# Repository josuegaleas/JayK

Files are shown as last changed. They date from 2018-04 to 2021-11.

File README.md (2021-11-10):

# JayK
Full-size mechanical keyboard with USB-C and no lighting, inspired by the [ONO-SENDAI MATRIX 83](https://imgur.com/a/v5pzh#FiXKcm0).

JayK Pro with *more* features can be found [here](https://github.com/josuegaleas/JayK-Pro).

### Disclaimer
I have not printed this PCB out yet, and I am not 100% certain the design works. Please print with discretion.

## Features
- TMK-based firmware
- Numpad on the left for comfort
- USB-C port for modernness
- No lighting for less complexity and lower cost

## Layout
### Default Layer
Default Layer
### Other Layers
Other Layers

JSON files for these layouts can be found [here](https://gist.github.com/josuegaleas/417a4ff5fc216ecdc7868effc9a7b36f) and [here](https://gist.github.com/josuegaleas/c81fd5085f4eeaf2fcede5950b9f7410), for editing in [KLE](http://www.keyboard-layout-editor.com/).

## Major Components
- Microcontroller — [Microchip's AT90USB1286](https://www.microchip.com/wwwproducts/en/AT90USB1286)
- USB-C Port — [Amphenol's 12401610E4#2A](https://www.amphenol-icc.com/usb-3-1-type-c-gen-2-12401610e42a.html)
- Crystal — [EPSON's FA-238](https://www5.epsondevice.com/en/products/crystal_unit/fa238.html)

## Tools
- Layout — [Keyboard Layout Editor](http://www.keyboard-layout-editor.com/)
- PCB — [KiCad EDA](https://kicad.org/)
- Firmware
	- [tmk_core](https://github.com/tmk/tmk_core)
	- [avr-gcc](https://www.gnu.org/software/gcc/gcc.html)
	- [dfu-programmer](https://dfu-programmer.sourceforge.io/)
- Models — [Plate & Case Builder](http://builder.swillkb.com/)

### KiCad Libraries
- [kicad_lib_tmk](https://github.com/tmk/kicad_lib_tmk)
- [keyboard_parts.pretty](https://github.com/tmk/keyboard_parts.pretty)
- [keebs.pretty](https://github.com/egladman/keebs.pretty)
- [jay-kicad-lib](https://github.com/josuegaleas/jay-kicad-lib)

## Development
Clone this repository with:
```bash
git clone --recursive https://github.com/josuegaleas/JayK.git
```

### Hardware
Within KiCad, navigate to the `PCB` folder and open `JayK.pro`.

Using a grid size of `0.0234375` inches for editing the layout.

### Software
Firmware can be compiled using `make` within the `Firmware` folder.

Refer to [this](https://github.com/tmk/tmk_keyboard/blob/master/tmk_core/doc/build.md) for dependencies and programming.

## References
- Layout — [Physical Keyboard Layouts Explained In Detail](https://drop.com/talk/947/physical-keyboard-layouts-explained-in-detail)
- PCB
	- [Keyboard PCB Guide](https://github.com/ruiqimao/keyboard-pcb-guide)
	- [Teensy++ 2.0 USB Development Board](https://www.pjrc.com/store/teensypp.html)
	- [Microchip's AT90USBKEY](https://www.microchip.com/DevelopmentTools/ProductDetails/AT90USBKEY2)
- Firmware
	- [TMK Keyboard Firmware Collection](https://github.com/tmk/tmk_keyboard/)
	- [How to build your very own keyboard firmware](https://deskthority.net/viewtopic.php?f=7&t=7177&start=)

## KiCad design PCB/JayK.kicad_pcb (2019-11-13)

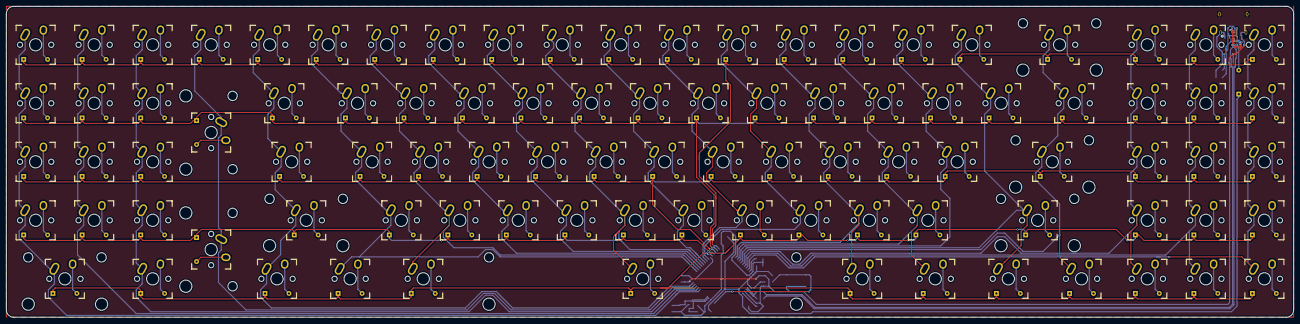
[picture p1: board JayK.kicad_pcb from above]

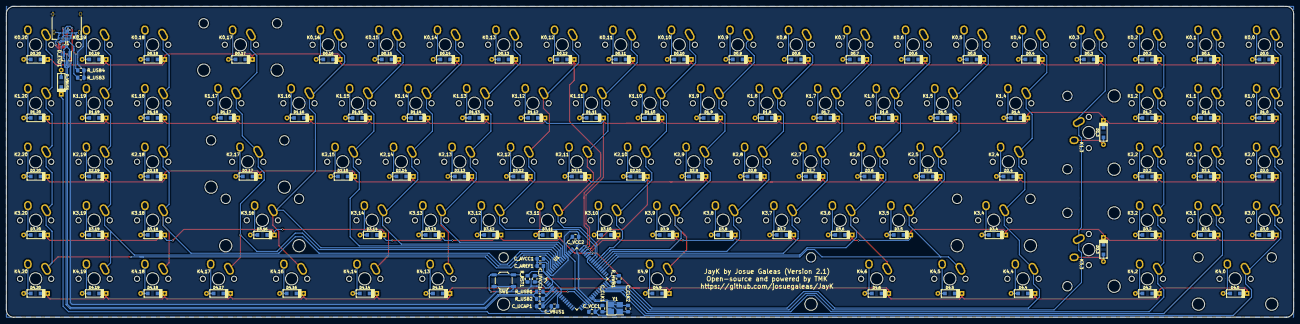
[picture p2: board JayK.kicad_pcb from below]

Board: 2 copper layers, 419.1 x 101.2 mm, 207 parts (114 on the bottom side), 134 nets.

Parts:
C_AREF1: 100n; C_0805_2012Metric_Pad1.15x1.40mm_HandSolder
C_AVCC1: 100n; C_0805_2012Metric_Pad1.15x1.40mm_HandSolder
C_CLK1, C_CLK2: 22p; C_0805_2012Metric_Pad1.15x1.40mm_HandSolder
C_UCAP1: 1u; C_0805_2012Metric_Pad1.15x1.40mm_HandSolder
C_UVCC1: 100n; C_0805_2012Metric_Pad1.15x1.40mm_HandSolder
C_VBUS1: 10u; C_0805_2012Metric_Pad1.15x1.40mm_HandSolder
C_VCC1, C_VCC2: 100n; C_0805_2012Metric_Pad1.15x1.40mm_HandSolder
D0,0, D0,1, D0,2, D0,3, D0,4, D0,5, D0,6, D0,7, D0,8, D0,9, D0,10, D0,11, D0,12, D0,13, D0,14, D0,15, D0,16, D0,17, D0,18, D0,19, D0,20, D1,0, D1,1, D1,2, D1,3, D1,4, D1,5, D1,6, D1,7, D1,8, D1,9, D1,10, D1,11, D1,12, D1,13, D1,14, D1,15, D1,16, D1,17, D1,18, D1,19, D1,20, D2,0, D2,1, D2,2, D2,4, D2,5, D2,6, D2,7, D2,8, D2,9, D2,10, D2,11, D2,12, D2,13, D2,14, D2,15, D2,17, D2,18, D2,19, D2,20, D3,0, D3,1, D3,2, D3,3, D3,4, D3,5, D3,6, D3,7, D3,8, D3,9, D3,10, D3,11, D3,12, D3,13, D3,14, D3,16, D3,18, D3,19, D3,20, D4,0, D4,2, D4,4, D4,5, D4,6, D4,9, D4,13, D4,14, D4,16, D4,17, D4,18, D4,19, D4,20: D; D_SOD123_axial
D_ESD1: PESD5V0L2BT; SOT-23_Handsoldering
D_VBUS1: D; D_SOD123_axial
J1: USB_C_Receptacle_USB2.0; USB_C_Receptacle_Amphenol_12401610E4-2A
K0,0, K0,1, K0,2, K0,3, K0,4, K0,5, K0,6, K0,7, K0,8, K0,9, K0,10, K0,11, K0,12, K0,13, K0,14, K0,15, K0,16, K0,18, K0,19, K0,20, K1,0, K1,1, K1,2, K1,5, K1,6, K1,7, K1,8, K1,9, K1,10, K1,11, K1,12, K1,13, K1,14, K1,15, K1,16, K1,18, K1,19, K1,20, K2,0, K2,1, K2,2, K2,5, K2,6, K2,7, K2,8, K2,9, K2,10, K2,11, K2,12, K2,13, K2,14, K2,15, K2,18, K2,19, K2,20, K3,0, K3,1, K3,2, K3,5, K3,6, K3,7, K3,8, K3,9, K3,10, K3,11, K3,12, K3,13, K3,14, K3,18, K3,19, K3,20, K4,2, K4,18, K4,19, K4,20: KEYSW; Mx_Alps_100
K0,17, K1,3, K3,3, K4,0: KEYSW; Mx_Alps_200
K1,4, K1,17: KEYSW; Mx_Alps_150
K2,4: KEYSW; Mx_Alps_175
K2,17, K3,4: KEYSW; Mx_Alps_225
K3,16: KEYSW; Mx_Alps_275
K4,4, K4,5, K4,6, K4,13, K4,14, K4,16, K4,17: KEYSW; Mx_Alps_125
K4,9: KEYSW; Mx_Alps_625
R_HWB1: 1k; R_0805_2012Metric_Pad1.15x1.40mm_HandSolder
R_RST1: 47k; R_0805_2012Metric_Pad1.15x1.40mm_HandSolder
R_USB1, R_USB2: 22; R_0805_2012Metric_Pad1.15x1.40mm_HandSolder
R_USB3, R_USB4: 5.1k; R_0805_2012Metric_Pad1.15x1.40mm_HandSolder
SW1: SW_PUSH; SW_SPST_TL3342
U1: AT90USB1286-AU; TQFP-64_14x14mm_P0.8mm
Y1: 16M; Crystal_SMD_SeikoEpson_FA238-4Pin_3.2x2.5mm_HandSoldering

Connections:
/CLK_N: C_CLK2.1, U1.24, Y1.3
/CLK_P: C_CLK1.1, U1.23, Y1.1
/D_+: R_USB2.1, U1.5
/D_-: R_USB1.1, U1.4
/D_N: D_ESD1.1, J1.A7, J1.B7, R_USB1.2
/D_P: D_ESD1.2, J1.A6, J1.B6, R_USB2.2
/col00: K0,0.1, K1,0.1, K2,0.1, K3,0.1, K4,0.1, U1.28
/col01: K0,1.1, K1,1.1, K2,1.1, K3,1.1, U1.29
/col02: K0,2.1, K1,2.1, K2,2.1, K3,2.1, K4,2.1, U1.30
/col03: K0,3.1, K1,3.1, K3,3.1, U1.31
/col04: K0,4.1, K1,4.1, K2,4.1, K3,4.1, K4,4.1, U1.32
/col05: K0,5.1, K1,5.1, K2,5.1, K3,5.1, K4,5.1, U1.35
/col06: K0,6.1, K1,6.1, K2,6.1, K3,6.1, K4,6.1, U1.36
/col07: K0,7.1, K1,7.1, K2,7.1, K3,7.1, U1.37
/col08: K0,8.1, K1,8.1, K2,8.1, K3,8.1, U1.38
/col09: K0,9.1, K1,9.1, K2,9.1, K3,9.1, K4,9.1, U1.39
/col10: K0,10.1, K1,10.1, K2,10.1, K3,10.1, U1.40
/col11: K0,11.1, K1,11.1, K2,11.1, K3,11.1, U1.41
/col12: K0,12.1, K1,12.1, K2,12.1, K3,12.1, U1.42
/col13: K0,13.1, K1,13.1, K2,13.1, K3,13.1, K4,13.1, U1.54
/col14: K0,14.1, K1,14.1, K2,14.1, K3,14.1, K4,14.1, U1.55
/col15: K0,15.1, K1,15.1, K2,15.1, U1.56
/col16: K0,16.1, K1,16.1, K3,16.1, K4,16.1, U1.57
/col17: K0,17.1, K1,17.1, K2,17.1, K4,17.1, U1.58
/col18: K0,18.1, K1,18.1, K2,18.1, K3,18.1, K4,18.1, U1.59
/col19: K0,19.1, K1,19.1, K2,19.1, K3,19.1, K4,19.1, U1.60
/col20: K0,20.1, K1,20.1, K2,20.1, K3,20.1, K4,20.1, U1.61
/row0: D0,0.1, D0,1.1, D0,2.1, D0,3.1, D0,4.1, D0,5.1, D0,6.1, D0,7.1, D0,8.1, D0,9.1, D0,10.1, D0,11.1, D0,12.1, D0,13.1, D0,14.1, D0,15.1, D0,16.1, D0,17.1, D0,18.1, D0,19.1, D0,20.1, U1.48
/row1: D1,0.1, D1,1.1, D1,2.1, D1,3.1, D1,4.1, D1,5.1, D1,6.1, D1,7.1, D1,8.1, D1,9.1, D1,10.1, D1,11.1, D1,12.1, D1,13.1, D1,14.1, D1,15.1, D1,16.1, D1,17.1, D1,18.1, D1,19.1, D1,20.1, U1.47
/row2: D2,0.1, D2,1.1, D2,2.1, D2,4.1, D2,5.1, D2,6.1, D2,7.1, D2,8.1, D2,9.1, D2,10.1, D2,11.1, D2,12.1, D2,13.1, D2,14.1, D2,15.1, D2,17.1, D2,18.1, D2,19.1, D2,20.1, U1.46
/row3: D3,0.1, D3,1.1, D3,2.1, D3,3.1, D3,4.1, D3,5.1, D3,6.1, D3,7.1, D3,8.1, D3,9.1, D3,10.1, D3,11.1, D3,12.1, D3,13.1, D3,14.1, D3,16.1, D3,18.1, D3,19.1, D3,20.1, U1.45
/row4: D4,0.1, D4,2.1, D4,4.1, D4,5.1, D4,6.1, D4,9.1, D4,13.1, D4,14.1, D4,16.1, D4,17.1, D4,18.1, D4,19.1, D4,20.1, U1.44
GND: C_AREF1.2, C_AVCC1.2, C_CLK1.2, C_CLK2.2, C_UCAP1.2, C_UVCC1.2, C_VBUS1.2, C_VCC1.2, C_VCC2.2, D_ESD1.3, J1.A1, J1.A12, J1.B1, J1.B12, J1.S1, R_HWB1.1, R_USB3.2, R_USB4.2, SW1.1, U1.6, U1.22, U1.53, U1.63, Y1.2, Y1.4
unnamed: C_AREF1.1, U1.62
unnamed: C_UCAP1.1, U1.7
unnamed: D0,0.2, K0,0.2
unnamed: D0,1.2, K0,1.2
unnamed: D0,2.2, K0,2.2
unnamed: D0,3.2, K0,3.2
unnamed: D0,4.2, K0,4.2
unnamed: D0,5.2, K0,5.2
unnamed: D0,6.2, K0,6.2
unnamed: D0,7.2, K0,7.2
unnamed: D0,8.2, K0,8.2
unnamed: D0,9.2, K0,9.2
unnamed: D0,10.2, K0,10.2
unnamed: D0,11.2, K0,11.2
unnamed: D0,12.2, K0,12.2
unnamed: D0,13.2, K0,13.2
unnamed: D0,14.2, K0,14.2
unnamed: D0,15.2, K0,15.2
unnamed: D0,16.2, K0,16.2
unnamed: D0,17.2, K0,17.2
unnamed: D0,18.2, K0,18.2
unnamed: D0,19.2, K0,19.2
unnamed: D0,20.2, K0,20.2
unnamed: D1,0.2, K1,0.2
unnamed: D1,1.2, K1,1.2
unnamed: D1,2.2, K1,2.2
unnamed: D1,3.2, K1,3.2
unnamed: D1,4.2, K1,4.2
unnamed: D1,5.2, K1,5.2
unnamed: D1,6.2, K1,6.2
unnamed: D1,7.2, K1,7.2
unnamed: D1,8.2, K1,8.2
unnamed: D1,9.2, K1,9.2
unnamed: D1,10.2, K1,10.2
unnamed: D1,11.2, K1,11.2
unnamed: D1,12.2, K1,12.2
unnamed: D1,13.2, K1,13.2
unnamed: D1,14.2, K1,14.2
unnamed: D1,15.2, K1,15.2
unnamed: D1,16.2, K1,16.2
unnamed: D1,17.2, K1,17.2
unnamed: D1,18.2, K1,18.2
unnamed: D1,19.2, K1,19.2
unnamed: D1,20.2, K1,20.2
unnamed: D2,0.2, K2,0.2
unnamed: D2,1.2, K2,1.2
unnamed: D2,2.2, K2,2.2
unnamed: D2,4.2, K2,4.2
unnamed: D2,5.2, K2,5.2
unnamed: D2,6.2, K2,6.2
unnamed: D2,7.2, K2,7.2
unnamed: D2,8.2, K2,8.2
unnamed: D2,9.2, K2,9.2
unnamed: D2,10.2, K2,10.2
unnamed: D2,11.2, K2,11.2
unnamed: D2,12.2, K2,12.2
unnamed: D2,13.2, K2,13.2
unnamed: D2,14.2, K2,14.2
unnamed: D2,15.2, K2,15.2
unnamed: D2,17.2, K2,17.2
unnamed: D2,18.2, K2,18.2
unnamed: D2,19.2, K2,19.2
unnamed: D2,20.2, K2,20.2
unnamed: D3,0.2, K3,0.2
unnamed: D3,1.2, K3,1.2
unnamed: D3,2.2, K3,2.2
unnamed: D3,3.2, K3,3.2
unnamed: D3,4.2, K3,4.2
unnamed: D3,5.2, K3,5.2
unnamed: D3,6.2, K3,6.2
unnamed: D3,7.2, K3,7.2
unnamed: D3,8.2, K3,8.2
unnamed: D3,9.2, K3,9.2
unnamed: D3,10.2, K3,10.2
unnamed: D3,11.2, K3,11.2
unnamed: D3,12.2, K3,12.2
unnamed: D3,13.2, K3,13.2
unnamed: D3,14.2, K3,14.2
unnamed: D3,16.2, K3,16.2
unnamed: D3,18.2, K3,18.2
unnamed: D3,19.2, K3,19.2
unnamed: D3,20.2, K3,20.2
unnamed: D4,0.2, K4,0.2
unnamed: D4,2.2, K4,2.2
unnamed: D4,4.2, K4,4.2
unnamed: D4,5.2, K4,5.2
unnamed: D4,6.2, K4,6.2
unnamed: D4,9.2, K4,9.2
unnamed: D4,13.2, K4,13.2
unnamed: D4,14.2, K4,14.2
unnamed: D4,16.2, K4,16.2
unnamed: D4,17.2, K4,17.2
unnamed: D4,18.2, K4,18.2
unnamed: D4,19.2, K4,19.2
unnamed: D4,20.2, K4,20.2
unnamed: D_VBUS1.2, J1.A4, J1.A9, J1.B4, J1.B9
unnamed: J1.A5, R_USB3.1
unnamed: J1.B5, R_USB4.1
unnamed: R_HWB1.2, U1.43
unnamed: R_RST1.1, SW1.2, U1.20
VCC: C_AVCC1.1, C_UVCC1.1, C_VBUS1.1, C_VCC1.1, C_VCC2.1, D_VBUS1.1, R_RST1.2, U1.3, U1.8, U1.21, U1.52, U1.64

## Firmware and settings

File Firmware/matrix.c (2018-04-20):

/*
 * Author: Josue Galeas
 * Last Edit: 2018.04.20
 */

#include <stdint.h>
#include <stdbool.h>
#include <avr/io.h>
#include <util/delay.h>
#include "print.h"
#include "debug.h"
#include "util.h"
#include "matrix.h"

#ifndef DEBOUNCE
#define DEBOUNCE 5
#endif

static const matrix_row_t one = 1;
static uint8_t debouncing = DEBOUNCE;
static matrix_row_t matrix[MATRIX_ROWS];
static matrix_row_t matrix_debouncing[MATRIX_ROWS];

static void init_cols(void);
static matrix_row_t read_cols(void);
static void unselect_rows(void);
static void select_row(uint8_t row);

void matrix_init(void)
{
	unselect_rows();
	init_cols();

	for (uint8_t i = 0; i < MATRIX_ROWS; i++)
	{
		matrix[i] = 0;
		matrix_debouncing[i] = 0;
	}
}

uint8_t matrix_scan(void)
{
	for (uint8_t i = 0; i < MATRIX_ROWS; i++)
	{
		select_row(i);
		_delay_us(30); /* FIXME: Is this the right amount of time? */
		matrix_row_t cols = read_cols();

		if (matrix_debouncing[i] != cols)
		{
			matrix_debouncing[i] = cols;

			if (debouncing)
			{
				debug("Bounce: ");
				debug_hex(debouncing);
				debug("\n");
			}

			debouncing = DEBOUNCE;
		}
		unselect_rows();
	}

	if (debouncing)
	{
		if (--debouncing)
		{
			_delay_ms(1);
		}
		else
		{
			for (uint8_t i = 0; i < MATRIX_ROWS; i++)
			{
				matrix[i] = matrix_debouncing[i];
			}
		}
	}

	return 1;
}

inline matrix_row_t matrix_get_row(uint8_t row)
{
	return matrix[row];
}

static void init_cols(void)
{
	/* Columns 0-4 on PD3-7 */
	/* Columns 5-12 on PC0-7 */
	/* Columns 13-20 on PF7-0 */
	/* DDR: 0, PORT: 1 */

	DDRD &= ~0b11111000;
	PORTD |= 0b11111000;

	DDRC &= ~0b11111111;
	PORTC |= 0b11111111;

	DDRF &= ~0b11111111;
	PORTF |= 0b11111111;
}

static matrix_row_t read_cols(void)
{
	/* Columns 0-4 on PD3-7 */
	/* Columns 5-12 on PC0-7 */
	/* Columns 13-20 on PF7-0 */

	return (PIND & (1 << 3) ? 0:(one << 0)) |
		(PIND & (1 << 4) ? 0:(one << 1)) |
		(PIND & (1 << 5) ? 0:(one << 2)) |
		(PIND & (1 << 6) ? 0:(one << 3)) |
		(PIND & (1 << 7) ? 0:(one << 4)) |
		(PINC & (1 << 0) ? 0:(one << 5)) |
		(PINC & (1 << 1) ? 0:(one << 6)) |
		(PINC & (1 << 2) ? 0:(one << 7)) |
		(PINC & (1 << 3) ? 0:(one << 8)) |
		(PINC & (1 << 4) ? 0:(one << 9)) |
		(PINC & (1 << 5) ? 0:(one << 10)) |
		(PINC & (1 << 6) ? 0:(one << 11)) |
		(PINC & (1 << 7) ? 0:(one << 12)) |
		(PINF & (1 << 7) ? 0:(one << 13)) |
		(PINF & (1 << 6) ? 0:(one << 14)) |
		(PINF & (1 << 5) ? 0:(one << 15)) |
		(PINF & (1 << 4) ? 0:(one << 16)) |
		(PINF & (1 << 3) ? 0:(one << 17)) |
		(PINF & (1 << 2) ? 0:(one << 18)) |
		(PINF & (1 << 1) ? 0:(one << 19)) |
		(PINF & (1 << 0) ? 0:(one << 20));
}

static void unselect_rows(void)
{
	/* Rows 0-4 on PA3-7 */
	/* DDR: 0, PORT: 0 */

	DDRA |= 0b11111000;
	PORTA |= 0b11111000;
}

static void select_row(uint8_t row)
{
	/* Rows 0-4 on PA3-7 */
	/* DDR: 1, PORT: 0 */

	DDRA |= (1 << (row + 3));
	PORTA &= ~(1 << (row + 3));
}

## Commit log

2017-01-30 Setting up libraries and working environments
    [PCB.kicad_pcb, PCB.sch]
2017-02-11 Added basic switch layout
    [PCB.kicad_pcb, PCB.sch]
2017-02-12 Oriented diodes; laid down MCU and BT module
    [PCB.kicad_pcb, PCB.sch]
2017-02-14 Switched MCUs; removed BT for now
    [PCB.kicad_pcb, PCB.sch]
2017-02-18 USB routed and most components connected
    [PCB.kicad_pcb, PCB.sch]
2017-02-20 Connected columns and rows
    [PCB.kicad_pcb]
2017-02-23 Additional routing: col1 and col2 connected
    [PCB.kicad_pcb]
2017-02-28 Trying a new MCU orientation to make room routes
    [PCB.kicad_pcb]
2017-02-28 Reached a roadblock with this orientation
    [PCB.kicad_pcb]
2017-03-01 Rotated MCU; rerouting
    [PCB.kicad_pcb]
2017-03-02 Connected many columns
    [PCB.kicad_pcb]
2017-03-03 All rows and columns connected
    [PCB.kicad_pcb]
2017-03-10 Started cleanup of routes and vias
    [PCB.kicad_pcb]
2017-03-22 More routing cleanup
    [PCB.kicad_pcb]
2017-05-17 Redid the layout to resemble the Teensy++ 2.0 more
    [PCB.kicad_pcb, PCB.sch]
2017-08-07 Removed unused footprint library; taking new design approach
2017-08-07 Taking new design approach; updated submodules
    [PCB.kicad_pcb, PCB.sch]
2017-11-08 2017.11.08 Update
    [PCB.kicad_pcb, PCB.sch]
2017-11-10 2017.11.10 Update
    - Updated README with more information
    - Updated layout slightly
    - Added a KiCad library for MCU
2017-11-12 2017.11.11 Nightly
    [JayKey1.kicad_pcb, JayKey1.sch, PCB.kicad_pcb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]
2017-11-14 2017.11.14 Nightly
    [JayKey1.sch]
2017-11-14 2017.11.14 Update
    - Redid schematic and layout
    - Now using USB-C connector
    [JayKey1.kicad_pcb, JayKey1.sch]
2017-11-16 2017.11.15 Update
    - Layed out most electronics on the board
    [JayKey1.kicad_pcb, JayKey1.sch]
2017-12-19 2017.12.19 Update
    [JayKey1.kicad_pcb]
2018-01-22 2018.01.22 Update
    - Most of the routing done for the new setup
    [JayKey1.kicad_pcb]
2018-01-24 2018.01.24 Update
    - Almost all routing complete
    - Only Vcc lines remain to connect
    [JayKey1.kicad_pcb]
2018-01-24 2018.01.24 Update 2
    - Vcc line now routed
    - Further cleanup is needed
    [JayKey1.kicad_pcb]
2018-01-25 2018.01.25 Update
    - Routing should be complete
    - Did more cleanup, GND lines/pins connected
    [JayKey1.kicad_pcb]
2018-03-16 2018.03.15 Update
    - Updated labels on switches and diodes to better match array subscripts
    - Started preliminary C code for the firmware
    [JayKey1.kicad_pcb, JayKey1.sch]
2018-03-19 2018.03.19 Update
    - Added led.c, necessary for compilation
    - Wrote matrix.c, however currently does not work
    - Updated README
    - Updated components list
    - Added firmware tools
    - Added new reference
    [matrix.c]
2018-03-20 2018.03.20 Update
    - Fixed shift count overflow
    - Removed unnecessary comments
    [matrix.c]
2018-03-28 2018.03.27 Update
    - Updated gitignore for KiCad files and C files
    - Renamed Models folder to Case
    - Deleted cache file
    - Updated readme with link to JayKey2
2018-04-16 2018.04.16 Nightly
    [JayKey1.kicad_pcb, JayKey1.sch]
2018-04-20 2018.04.20 Update
    - Official version 1.0 release
    - Cleaned up routing on PCB and moved components for a cleaner design
    - Made new constant in matrix.c called 'one' which makes read_cols function easier to read
    [JayKey1.kicad_pcb, JayKey1.sch]
2018-04-28 2018.04.27 Update
    - Version 1.1 Release
    - Cleaned up routing to the USB port
    - Made seperate schematic sheet with key matrix (so it can be used in JayKey2)
    [JayKey1.kicad_pcb, JayKey1.sch, key_matrix.sch]
2018-08-27 2018.08.27 Nightly
    [JayKey1.kicad_pcb, JayKey1.sch]
2018-08-28 2018.08.28 Nightly
    [JayKey1.sch]
2018-09-23 2018.09.23 Nightly
    [JayKey1.sch, key_matrix.sch, usb.sch]
2018-09-25 2018.09.25 Nightly
    [JayKey1.sch, usb.sch]
2018-09-29 2018.09.29 Nightly
    [JayKey1.kicad_pcb, JayKey1.sch, usb.sch]
2018-10-02 2018.10.02 Nightly
    [JayKey1.kicad_pcb, JayKey1.sch, key_matrix.sch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]
2018-10-12 2018.10.11 Nightly
    [JayKey1.kicad_pcb, JayKey1.sch, key_matrix.sch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]
2018-10-25 2018.10.25 Nightly
    [JayKey1.kicad_pcb, JayKey1.sch, usb.sch]
2018-11-29 2018.11.29 Nightly
    [JayKey1.sch, key_matrix.sch, usb.sch]
2018-12-04 2018.12.04 Nightly
    [JayKey1.kicad_pcb, JayKey1.sch, key_matrix.sch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]
2018-12-06 2018.12.06 Nightly
    [JayKey1.kicad_pcb]
2018-12-14 2018.12.14 Nightly
    [JayKey1.kicad_pcb]
2018-12-15 2018.12.14 Nightly 2
    [JayKey1.kicad_pcb, JayKey1.sch, usb.sch]
2018-12-15 2018.12.14 Update
    - Moved project to KiCad 5.0
    - Using my own KiCad library instead of doragasu's library
    - Re-did all the tracing; much cleaner design now
    - Moved components around to be more correctly placed
    - Updated footprints in accordance to 5.0's libraries
    - USB data lines and clock lines were made differential pairs for correctness
    - Added instruction to readme for development
    - No longer pursuing planned features
    - Will still work out any issues that arise
    - Shifting focus to case design and JayKey2
    [JayKey1.kicad_pcb, JayKey1.sch, key_matrix.sch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]
2019-11-13 2019.11.13 Update
    - Renamed from JayKey1 to JayK
    - Officially opened on KiCad 5.1 and known to be working
    - Added missing power flag on VBUS line from USB port
    - Fixed courtyard overlaps in layout
    - Added the apparently missing ground plane on the front side
    - Fixed issue #1
    [JayK.kicad_pcb, JayK.sch, JayKey1.kicad_pcb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]
2021-11-10 2021.11.09 Update
    - Updated link to KiCad's website, nothing else
    - More info here: https://forum.kicad.info/t/warning-avoid-all-links-to-kicad-pcb-org-use-kicad-org/31521
